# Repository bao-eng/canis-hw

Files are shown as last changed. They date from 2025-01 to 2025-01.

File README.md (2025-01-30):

# canis-hw
Isolated USB CAN-FD interface with SW-controllable termination resistors

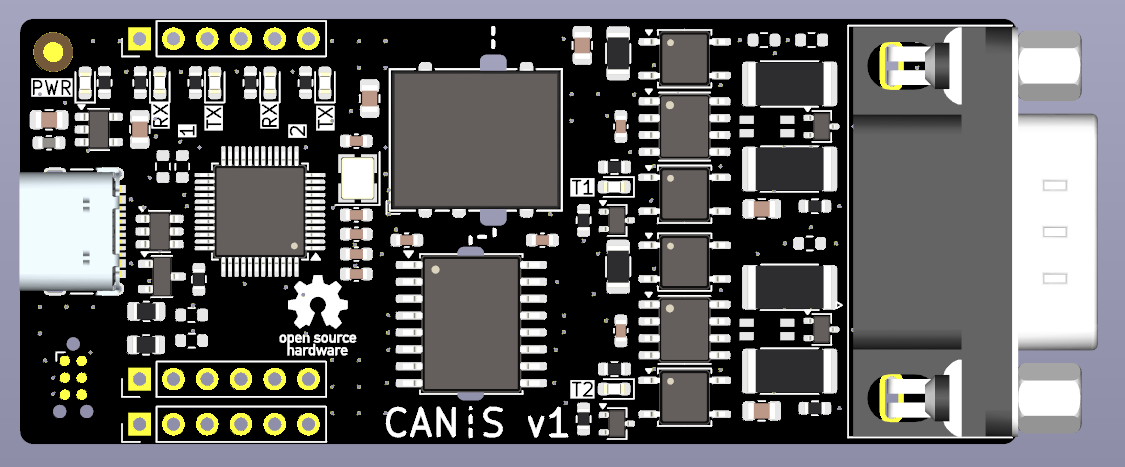
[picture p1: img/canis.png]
canis


## Features
- 2xCAN-FD interfaces supporting 8Mb/s
- 3kV isolation
- SW-controllable CAN-termination resistors
- 24V tolerant CAN transceivers and CAN termination circuit
- USB Type-C connector
- 2-layer PCB design
- Easy to solder 0603 components

## Firmware
Please use this candleLight_fw [fork](https://github.com/bao-eng/candleLight_fw/tree/canis)(canis branch). \
Prebuilt binary ```canis_fw.bin``` can be found in [releases](https://github.com/bao-eng/candleLight_fw/releases).
#### Flashing via DFU
- Short J2 pins ```1``` and ```2```
- Connect USB to the host PC
- Unshort J2
- In the ```lsusb``` output you should be able to see ```STMicroelectronics STM Device in DFU Mode```
- Run ```sudo dfu-util -d 0483:df11 -c 1 -i 0 -a 0 -s 0x08000000 -D canis_fw.bin```
- Reconnect USB
- In the ```lsusb``` output you should be able to see ```OpenMoko, Inc. Geschwister Schneider CAN adapter```
#### Flashing via SWD
- Connect ST-link to the J2
- Connect USB to the host PC
- Run ```st-flash write canis_fw.bin 0x08000000```
- Disconnect ST-link from J2
- Reconnect USB
- In the ```lsusb``` output you should be able to see ```OpenMoko, Inc. Geschwister Schneider CAN adapter```
## Usage
Bring up can0 interface and enable 120Ohm termination resistor:
```
ip link set can0 up type can bitrate 1000000 dbitrate 8000000 fd on termination 120
```
Disable 120Ohm termination resistor:
```
ip link set can0 type can termination 0
```

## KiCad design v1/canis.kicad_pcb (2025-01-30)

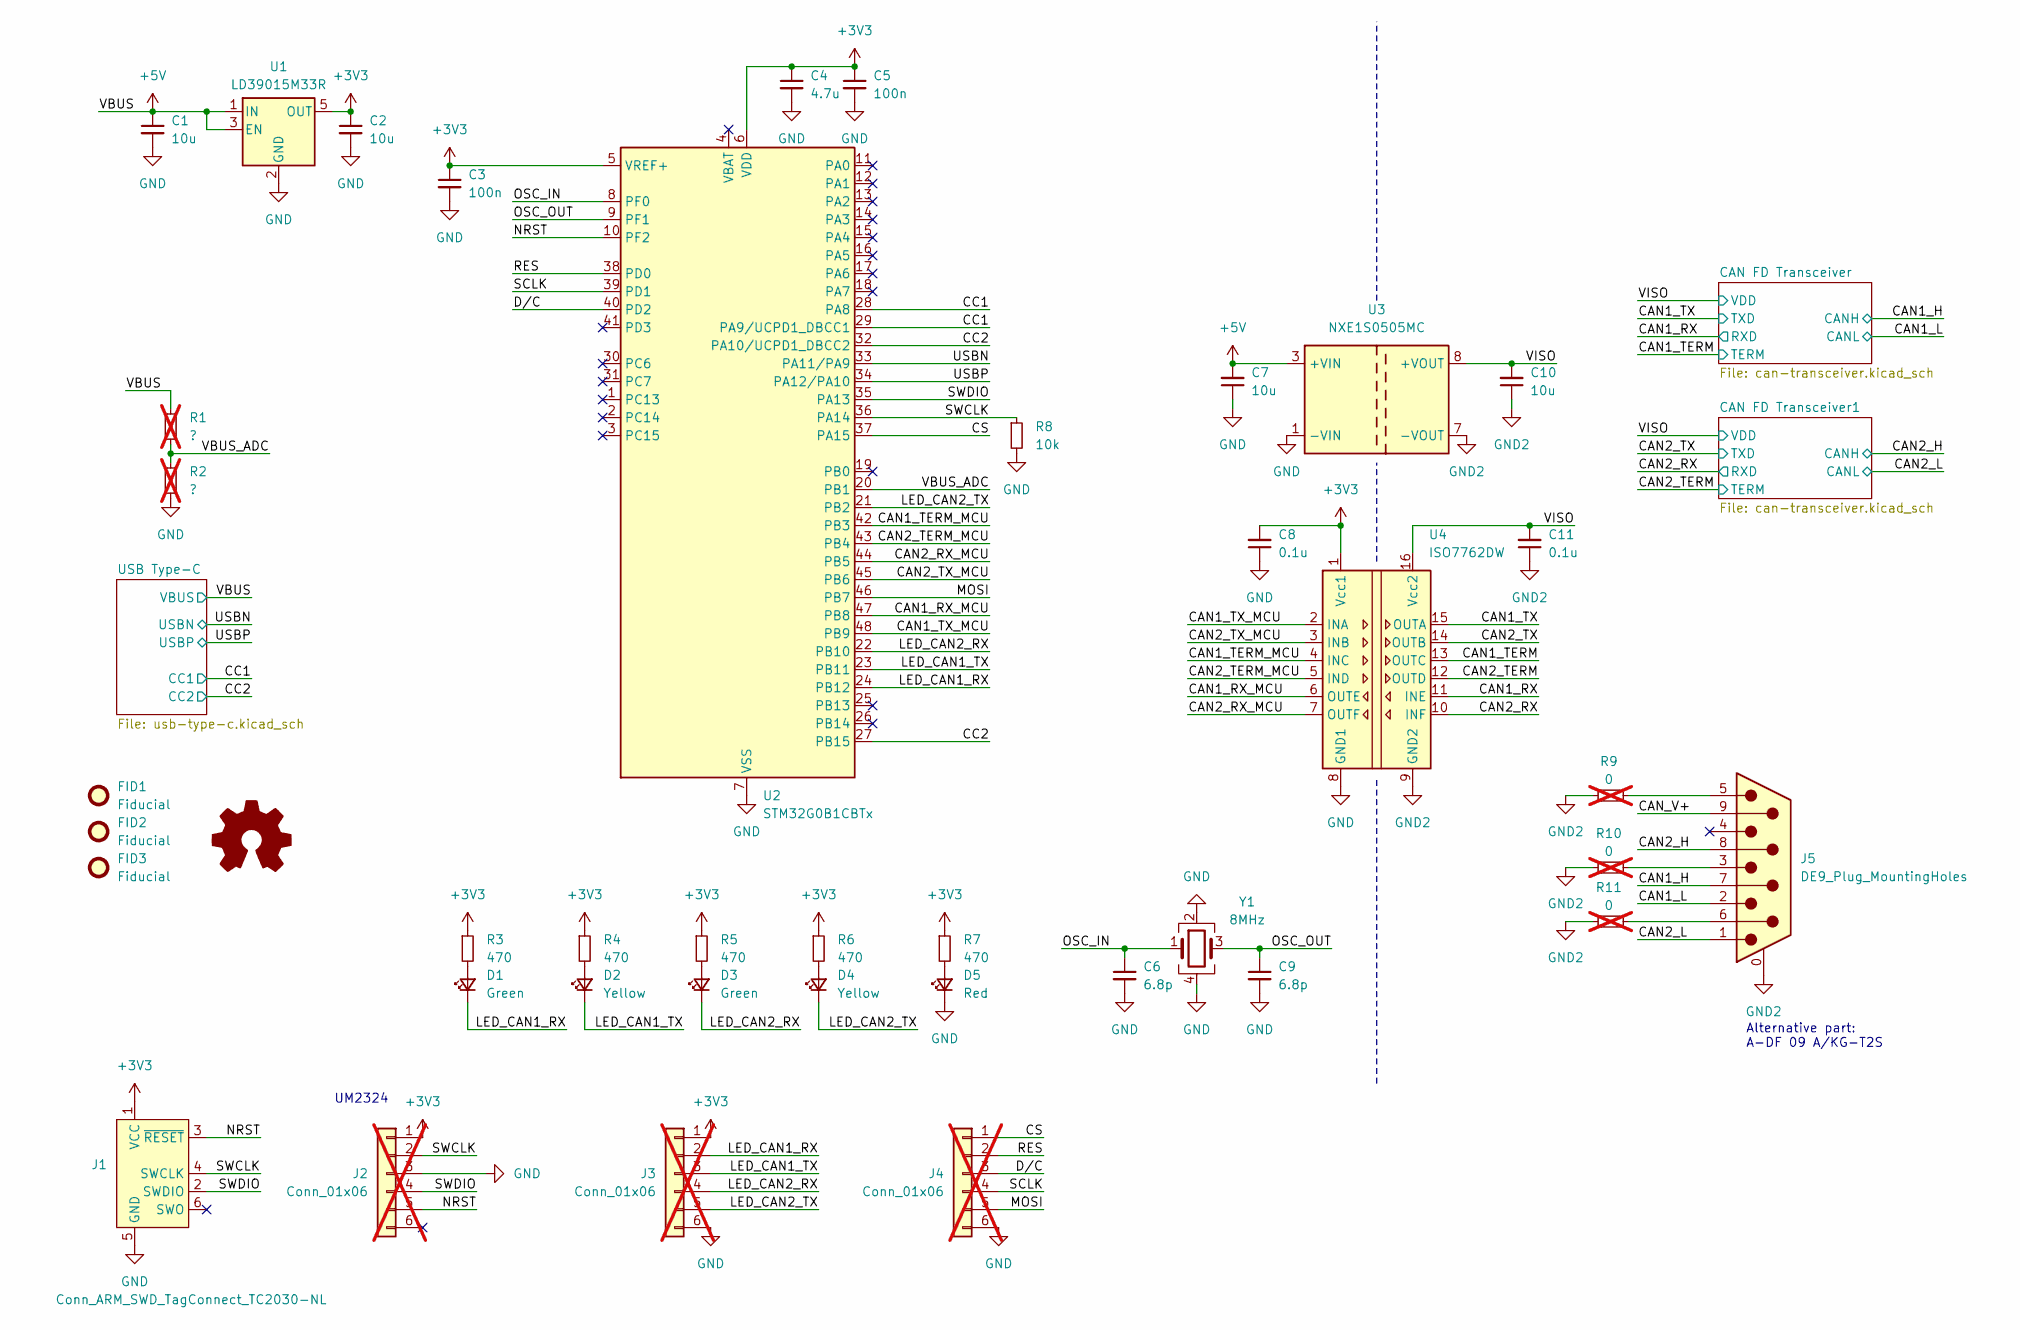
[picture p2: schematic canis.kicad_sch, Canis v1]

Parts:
C1, C2, C7, C10: 10u; C_0805_2012Metric; MPN 885012107010
C3, C5: 100n; C_0603_1608Metric; MPN 885012205018
C4: 4.7u; C_0603_1608Metric; MPN 885012106005
C6, C9: 6.8p; C_0603_1608Metric; MPN 885012006050
C8, C11: 0.1u; C_0603_1608Metric; MPN 885012205018
D1, D3: Green; LED_0603_1608Metric; MPN 150060VS75000
D2, D4: Yellow; LED_0603_1608Metric; MPN 150060YS75000
D5: Red; LED_0603_1608Metric; MPN 150060SS75000
FID1, FID2, FID3: Fiducial; Fiducial_1.5mm_Mask3mm
J1: Conn_ARM_SWD_TagConnect_TC2030-NL; Tag-Connect_TC2030-IDC-NL_2x03_P1.27mm_Vertical
J2, J3, J4: Conn_01x06; PinHeader_1x06_P2.54mm_Vertical; MPN 61300611121; not fitted
J5: DE9_Plug_MountingHoles; 618009231221; MPN 618009231221
R1, R2: ?; R_0603_1608Metric; not fitted
R3, R4, R5, R6, R7: 470; R_0603_1608Metric; MPN 560112116067
R8: 10k; R_0603_1608Metric; MPN 560112120019
R9, R10, R11: 0; R_0603_1608Metric; MPN 560112116001; not fitted
SYM1: Logo_Open_Hardware_Small; OSHW-Logo_5.7x6mm_SilkScreen
U1: LD39015M33R; SOT-23-5
U2: STM32G0B1CBTx; LQFP-48_7x7mm_P0.5mm
U3: NXE1S0505MC; Converter_DCDC_Murata_NXExSxxxxMC_SMD
U4: ISO7762DW; SOIC-16W_7.5x10.3mm_P1.27mm
Y1: 8MHz; Crystal_SMD_3225-4Pin_3.2x2.5mm; MPN 830108313809

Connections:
+3V3: C2.1, C3.1, C4.1, C5.1, C8.2, J1.1 (VCC), J2.1, J3.1, R3.1, R4.1, R5.1, R6.1, R7.1, U1.5 (OUT), U2.5 (VREF+), U2.6 (VDD), U4.1 (Vcc1)
+5V: C1.1, C7.2, R1.1, U1.1 (IN), U1.3 (EN), U3.3 (+VIN); also elsewhere on the board
/CAN1_H: J5.7; also elsewhere on the board
/CAN1_L: J5.2; also elsewhere on the board
/CAN1_RX: U4.11 (INE); also elsewhere on the board
/CAN1_RX_MCU: U2.47 (PB8), U4.6 (OUTE)
/CAN1_TERM: U4.13 (OUTC); also elsewhere on the board
/CAN1_TERM_MCU: U2.42 (PB3), U4.4 (INC)
/CAN1_TX: U4.15 (OUTA); also elsewhere on the board
/CAN1_TX_MCU: U2.48 (PB9), U4.2 (INA)
/CAN2_H: J5.8; also elsewhere on the board
/CAN2_L: J5.1; also elsewhere on the board
/CAN2_RX: U4.10 (INF); also elsewhere on the board
/CAN2_RX_MCU: U2.44 (PB5), U4.7 (OUTF)
/CAN2_TERM: U4.12 (OUTD); also elsewhere on the board
/CAN2_TERM_MCU: U2.43 (PB4), U4.5 (IND)
/CAN2_TX: U4.14 (OUTB); also elsewhere on the board
/CAN2_TX_MCU: U2.45 (PB6), U4.3 (INB)
/CAN_V+: J5.9
/CC1: U2.28 (PA8), U2.29 (PA9/UCPD1_DBCC1); also elsewhere on the board
/CC2: U2.27 (PB15), U2.32 (PA10/UCPD1_DBCC2); also elsewhere on the board
/CS: J4.1, U2.37 (PA15)
/D/C: J4.3, U2.40 (PD2)
/LED_CAN1_RX: D1.1 (K), J3.2, U2.24 (PB12)
/LED_CAN1_TX: D2.1 (K), J3.3, U2.23 (PB11)
/LED_CAN2_RX: D3.1 (K), J3.4, U2.22 (PB10)
/LED_CAN2_TX: D4.1 (K), J3.5, U2.21 (PB2)
/MOSI: J4.5, U2.46 (PB7)
/NRST: J1.3 (~RESET), J2.5, U2.10 (PF2)
/OSC_IN: C6.1, U2.8 (PF0), Y1.1
/OSC_OUT: C9.1, U2.9 (PF1), Y1.3
/RES: J4.2, U2.38 (PD0)
/SCLK: J4.4, U2.39 (PD1)
/SWCLK: J1.4 (SWCLK), J2.2, R8.1, U2.36 (PA14)
/SWDIO: J1.2 (SWDIO), J2.4, U2.35 (PA13)
/USBN: U2.33 (PA11/PA9); also elsewhere on the board
/USBP: U2.34 (PA12/PA10); also elsewhere on the board
/VBUS_ADC: R1.2, R2.1, U2.20 (PB1)
/VISO: C10.2, C11.2, U3.8 (+VOUT), U4.16 (Vcc2); also elsewhere on the board
GND: C1.2, C2.2, C3.2, C4.2, C5.2, C6.2, C7.1, C8.1, C9.2, D5.1 (K), J1.5 (GND), J2.3, J3.6, J4.6, R2.2, R8.2, U1.2 (GND), U2.7 (VSS), U3.1 (-VIN), U4.8 (GND1), Y1.2, Y1.4; also elsewhere on the board
GND2: C10.1, C11.1, J5.0 (PAD), R9.1, R10.1, R11.1, U3.7 (-VOUT), U4.9 (GND2); also elsewhere on the board
unnamed: D1.2 (A), R3.2
unnamed: D2.2 (A), R4.2
unnamed: D3.2 (A), R5.2
unnamed: D4.2 (A), R6.2
unnamed: D5.2 (A), R7.2
unnamed: J5.3, R10.2
unnamed: J5.5, R9.2
unnamed: J5.6, R11.2

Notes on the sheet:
UM2324
Alternative part: A-DF 09 A/KG-T2S

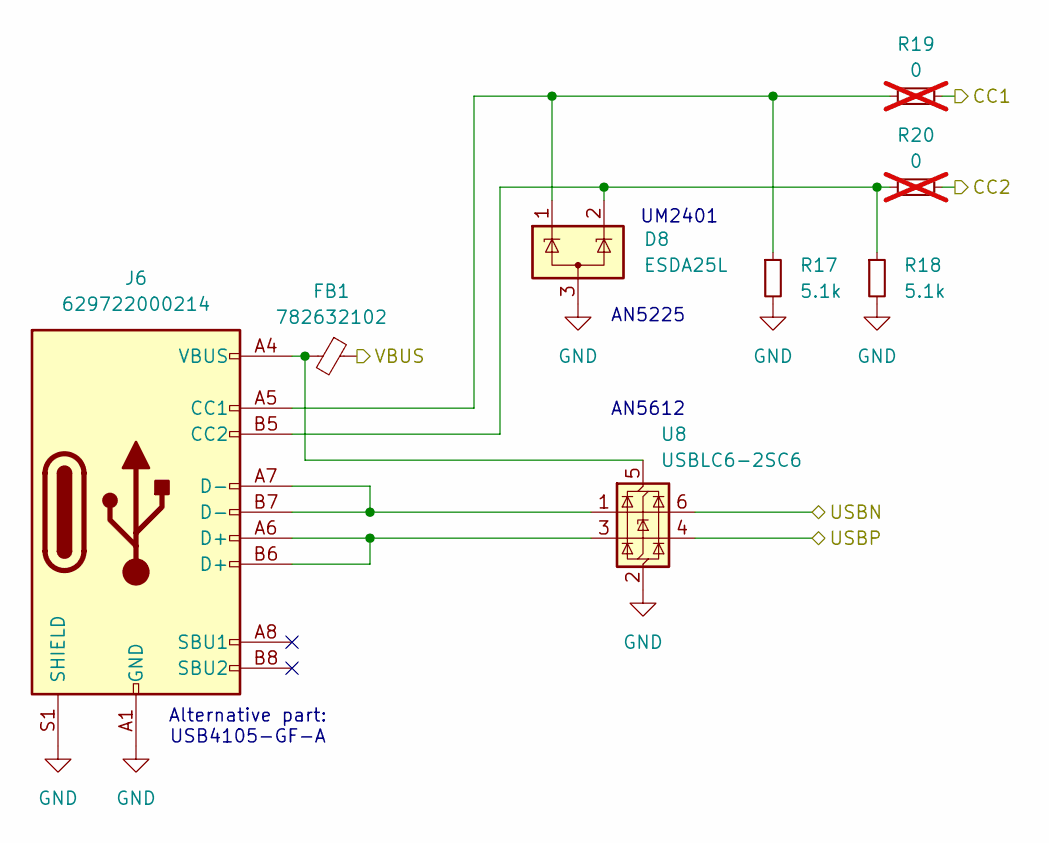
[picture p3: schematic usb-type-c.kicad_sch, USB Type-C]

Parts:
D8: ESDA25L; SOT-23-3
FB1: 782632102; L_0603_1608Metric
J6: 629722000214
R17, R18: 5.1k; R_0805_2012Metric; MPN 560112120019
R19, R20: 0; R_0603_1608Metric; MPN 560112116001; not fitted
U8: USBLC6-2SC6; SOT-23-6

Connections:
+5V: FB1.1; also elsewhere on the board
/CC1: R19.2; also elsewhere on the board
/CC2: R20.2; also elsewhere on the board
/USBN: U8.6 (I/O1); also elsewhere on the board
/USBP: U8.4 (I/O2); also elsewhere on the board
GND: D8.3 (A), J6.A1 (GND), J6.A12 (GND), J6.B1 (GND), J6.B12 (GND), J6.S1 (SHIELD), R17.2, R18.2, U8.2 (GND); also elsewhere on the board
unnamed: D8.1 (K), J6.A5 (CC1), R17.1, R19.1
unnamed: D8.2 (K), J6.B5 (CC2), R18.1, R20.1
unnamed: J6.A6 (D+), J6.B6 (D+), U8.3 (I/O2)
unnamed: J6.A7 (D-), J6.B7 (D-), U8.1 (I/O1)
unnamed: FB1.2, J6.A4 (VBUS), J6.A9 (VBUS), J6.B4 (VBUS), J6.B9 (VBUS), U8.5 (VBUS)

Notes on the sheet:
UM2401
AN5225
AN5612
Alternative part: USB4105-GF-A

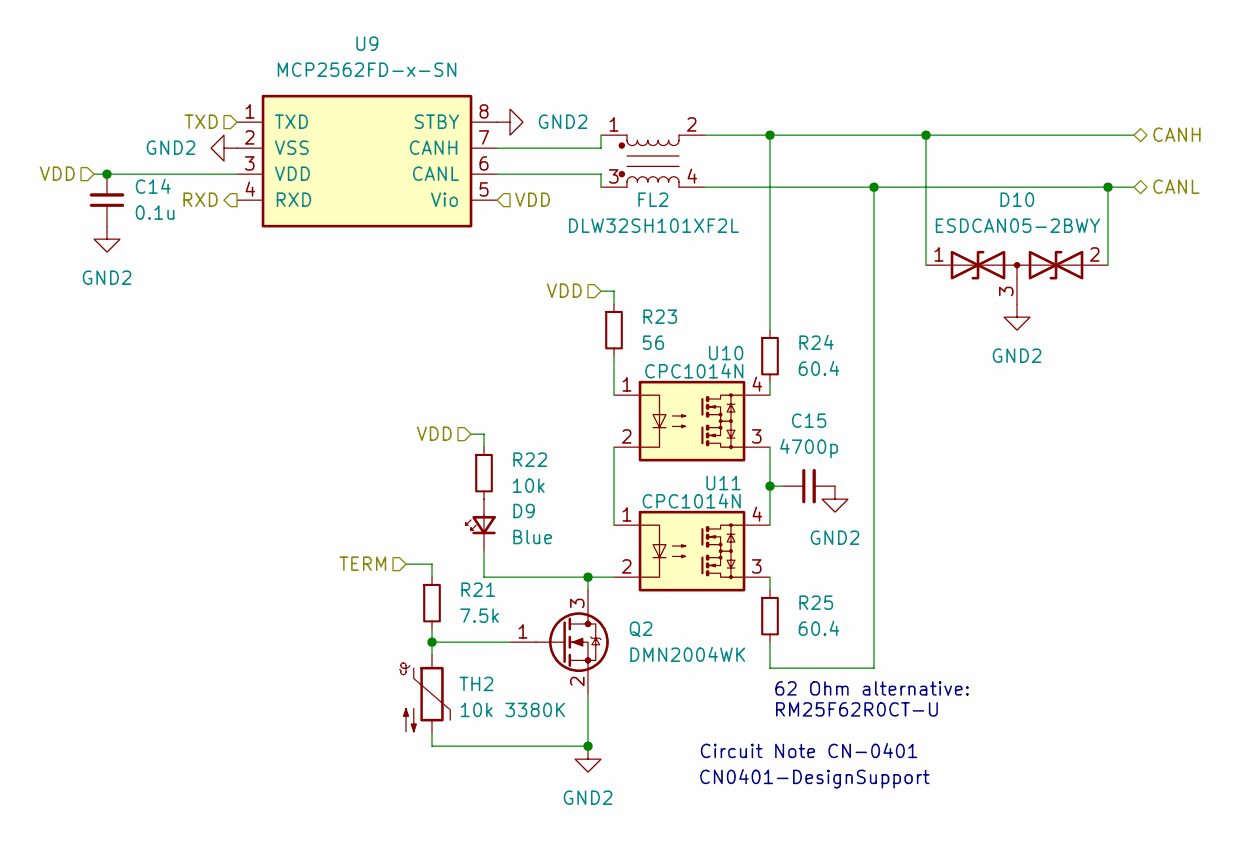
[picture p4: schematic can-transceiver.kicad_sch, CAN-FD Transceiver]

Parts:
C14: 0.1u; C_0603_1608Metric; MPN 885012205018
C15: 4700p; C_0805_2012Metric; MPN 885012207090
D9: Blue; LED_0603_1608Metric; MPN 150060BS75000
D10: ESDCAN05-2BWY; SOT-323_SC-70
FL2: DLW32SH101XF2L
Q2: DMN2004WK; SOT-323_SC-70
R21: 7.5k; R_0603_1608Metric; MPN 560112116005
R22: 10k; R_0603_1608Metric; MPN 560112116005
R23: 56; R_1206_3216Metric; MPN RC1206FR-0756RL
R24, R25: 60.4; R_2512_6332Metric; MPN 3504G3A60R4FTDF
TH2: 10k 3380K; R_0603_1608Metric; MPN NCU18XH103F6SRB
U9: MCP2562FD-x-SN; SOIC-8_3.9x4.9mm_P1.27mm
U10, U11: CPC1014N; SOP-4_3.8x4.1mm_P2.54mm

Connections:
/CAN2_H: D10.1 (A1), FL2.2, R24.1; also elsewhere on the board
/CAN2_L: D10.2 (A2), FL2.4, R25.2; also elsewhere on the board
/CAN2_RX: U9.4 (RXD); also elsewhere on the board
/CAN2_TERM: R21.1; also elsewhere on the board
/CAN2_TX: U9.1 (TXD); also elsewhere on the board
/VISO: C14.2, R22.1, R23.1, U9.3 (VDD), U9.5 (Vio); also elsewhere on the board
GND2: C14.1, C15.2, D10.3 (common), Q2.2 (S), TH2.2, U9.2 (VSS), U9.8 (STBY); also elsewhere on the board
unnamed: C15.1, U10.3, U11.4
unnamed: D9.2 (A), R22.2
unnamed: D9.1 (K), Q2.3 (D), U11.2
unnamed: Q2.1 (G), R21.2, TH2.1
unnamed: R23.2, U10.1
unnamed: R24.2, U10.4
unnamed: R25.1, U11.3
unnamed: FL2.1, U9.7 (CANH)
unnamed: FL2.3, U9.6 (CANL)
unnamed: U10.2, U11.1

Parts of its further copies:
C12: 0.1u; C_0603_1608Metric; MPN 885012205018
C13: 4700p; C_0805_2012Metric; MPN 885012207090
D6: Blue; LED_0603_1608Metric; MPN 150060BS75000
D7: ESDCAN05-2BWY; SOT-323_SC-70
FL1: DLW32SH101XF2L
Q1: DMN2004WK; SOT-323_SC-70
R12: 7.5k; R_0603_1608Metric; MPN 560112116005
R13: 10k; R_0603_1608Metric; MPN 560112116005
R14: 56; R_1206_3216Metric; MPN RC1206FR-0756RL
R15, R16: 60.4; R_2512_6332Metric; MPN 3504G3A60R4FTDF
TH1: 10k 3380K; R_0603_1608Metric; MPN NCU18XH103F6SRB
U5: MCP2562FD-x-SN; SOIC-8_3.9x4.9mm_P1.27mm
U6, U7: CPC1014N; SOP-4_3.8x4.1mm_P2.54mm

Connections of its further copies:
/CAN1_H: D7.1 (A1), FL1.2, R15.1; also elsewhere on the board
/CAN1_L: D7.2 (A2), FL1.4, R16.2; also elsewhere on the board
/CAN1_RX: U5.4 (RXD); also elsewhere on the board
/CAN1_TERM: R12.1; also elsewhere on the board
/CAN1_TX: U5.1 (TXD); also elsewhere on the board
/VISO: C12.2, R13.1, R14.1, U5.3 (VDD), U5.5 (Vio); also elsewhere on the board
GND2: C12.1, C13.2, D7.3 (common), Q1.2 (S), TH1.2, U5.2 (VSS), U5.8 (STBY); also elsewhere on the board
unnamed: C13.1, U6.3, U7.4
unnamed: D6.2 (A), R13.2
unnamed: D6.1 (K), Q1.3 (D), U7.2
unnamed: Q1.1 (G), R12.2, TH1.1
unnamed: R14.2, U6.1
unnamed: R15.2, U6.4
unnamed: R16.1, U7.3
unnamed: FL1.1, U5.7 (CANH)
unnamed: FL1.3, U5.6 (CANL)
unnamed: U6.2, U7.1

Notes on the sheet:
CN0401-DesignSupport
62 Ohm alternative: RM25F62R0CT-U
Circuit Note CN-0401

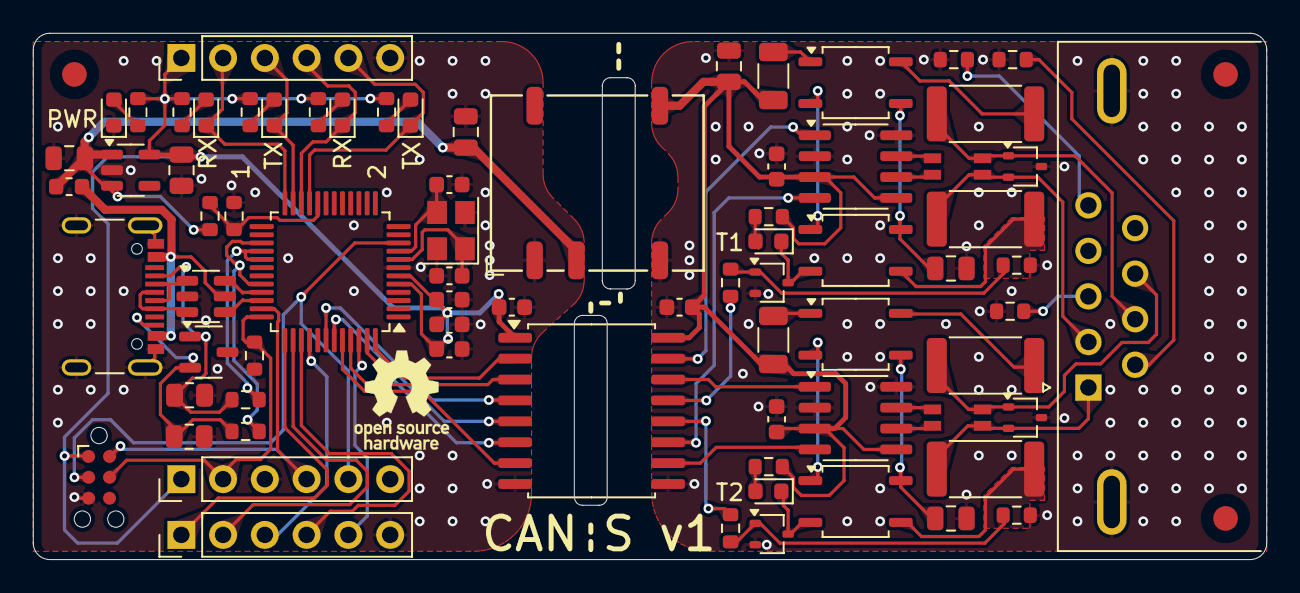
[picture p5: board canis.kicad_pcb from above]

Board: 2 copper layers, 75.0 x 32.0 mm, 79 parts (0 on the bottom side), 73 nets.
